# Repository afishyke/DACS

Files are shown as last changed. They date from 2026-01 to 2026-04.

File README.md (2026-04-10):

# DACS: Digital Automatic Changeover Switch

DACS is a discrete-logic power changeover controller that monitors grid health and switches loads between mains and inverter/battery supply. It is designed to avoid relay chatter by requiring sustained bad/good conditions before switching.

The full finite state machine (FSM), Boolean equations, and timing behavior are documented in `FSM/README.md`.

## What this project is

- A hardware-first automatic changeover system (no microcontroller in the switching core).
- A three-block architecture: sensing and conditioning, FSM decision logic, and relay output stage.
- A validated FSM implementation in both Logisim and Verilog.
- A delay-justification analysis pipeline for power-quality disturbance datasets.

## Visual overview

### 1) Full hardware architecture (KiCad)

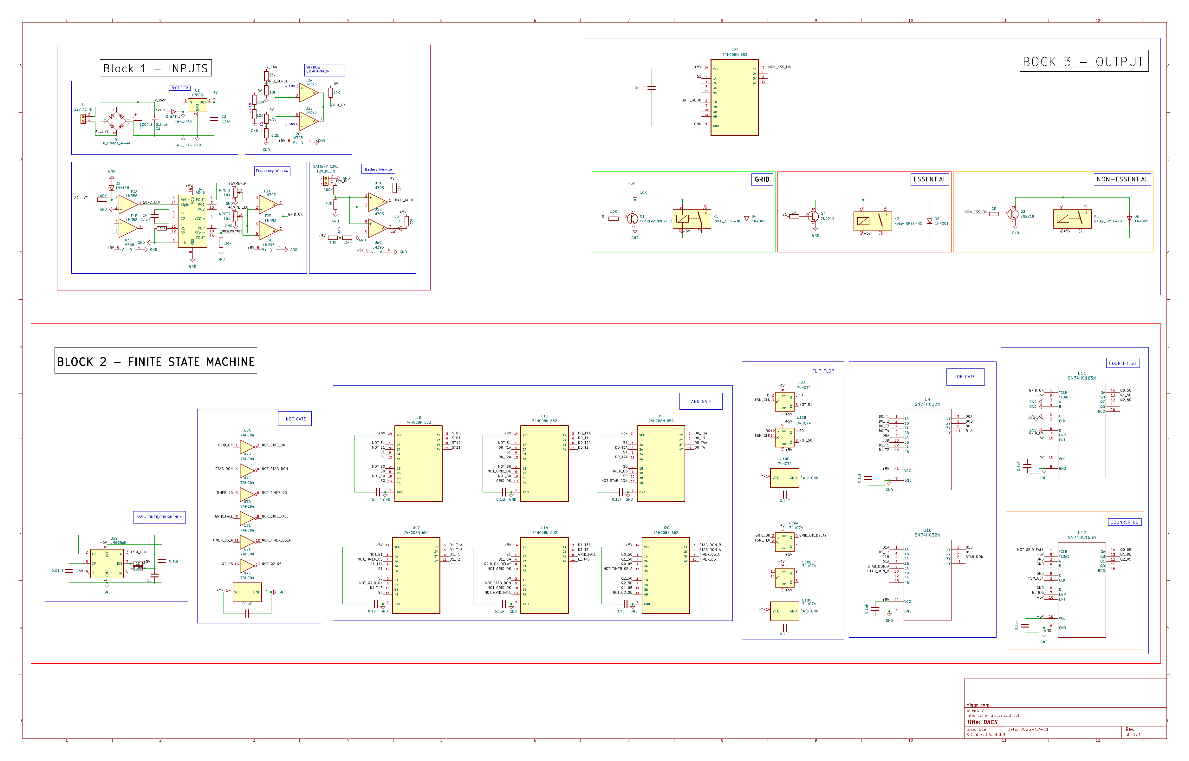
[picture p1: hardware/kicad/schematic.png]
DACS full schematic


### 2) GRID_OK comparator generation (LTspice)

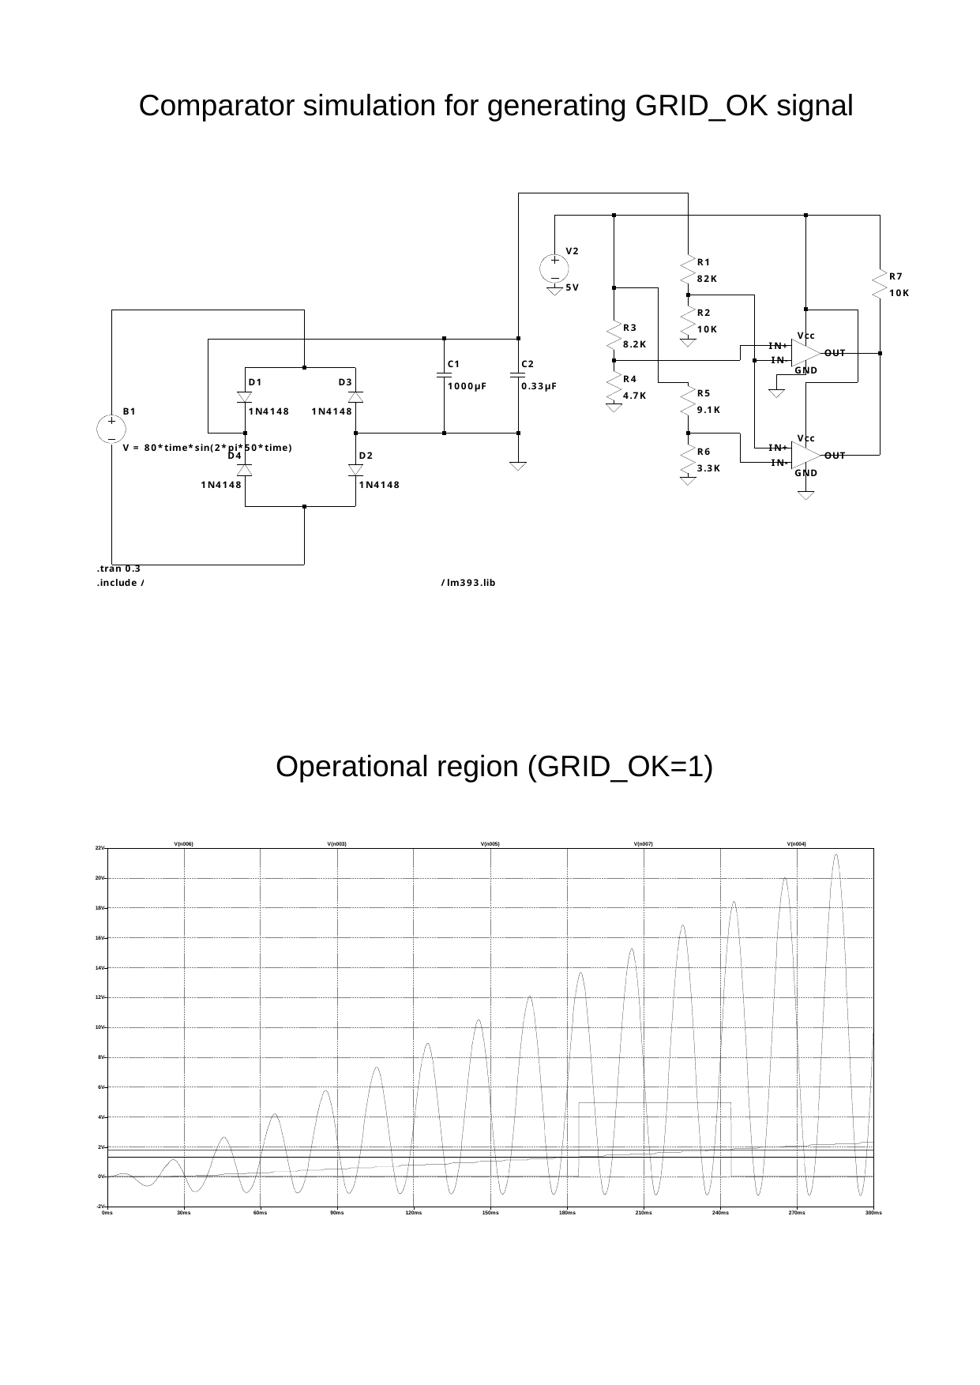
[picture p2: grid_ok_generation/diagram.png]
GRID_OK comparator simulation


### 3) Power-quality context plot

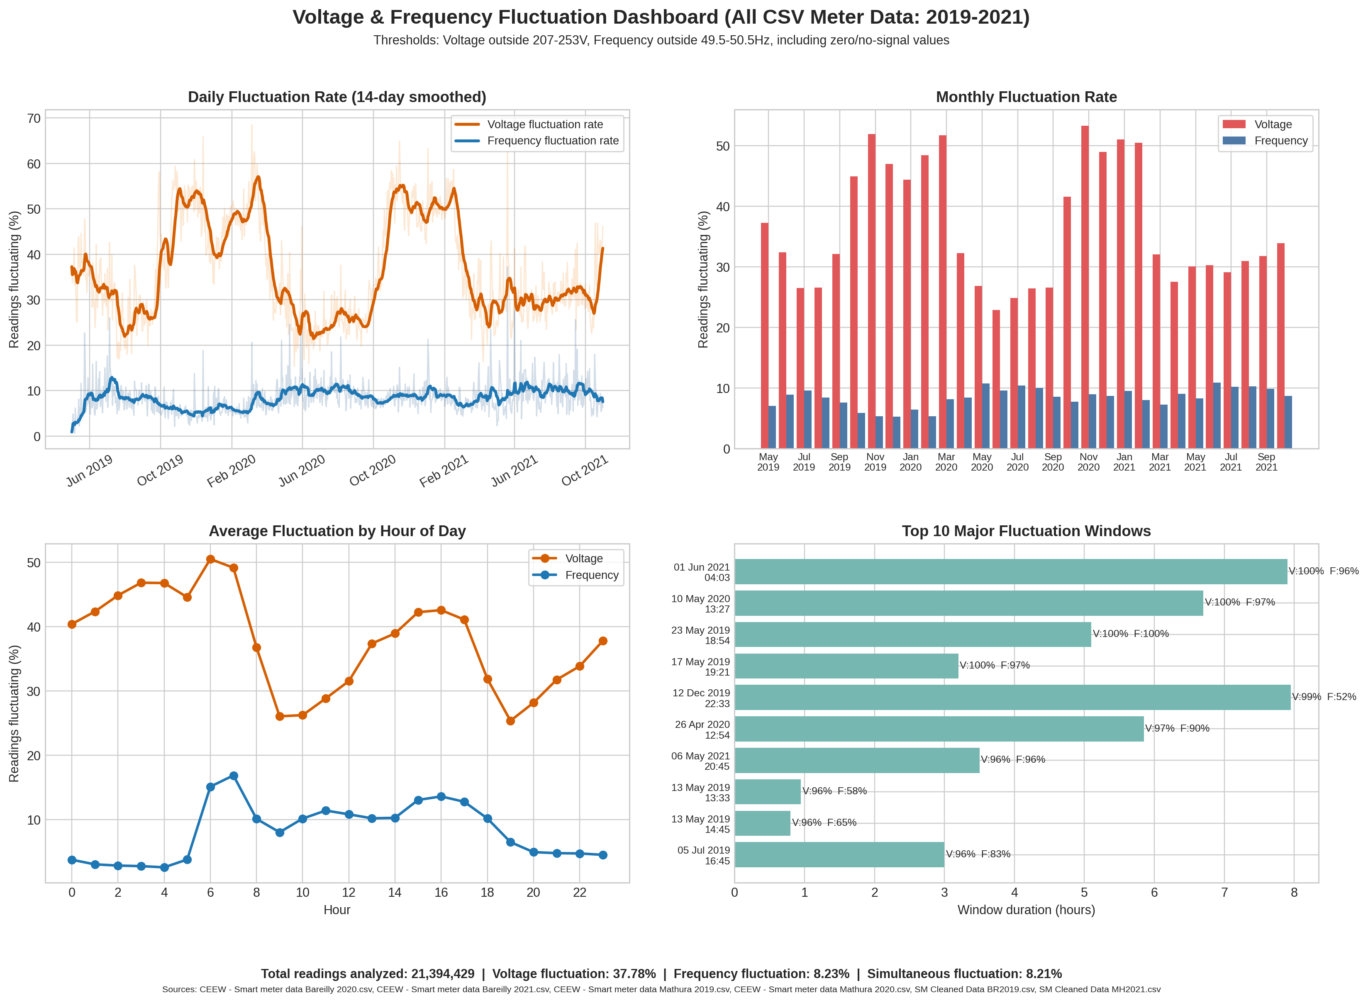
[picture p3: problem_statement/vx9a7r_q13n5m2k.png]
Problem statement plot


### 4) Disturbance class signal examples (delay analysis)

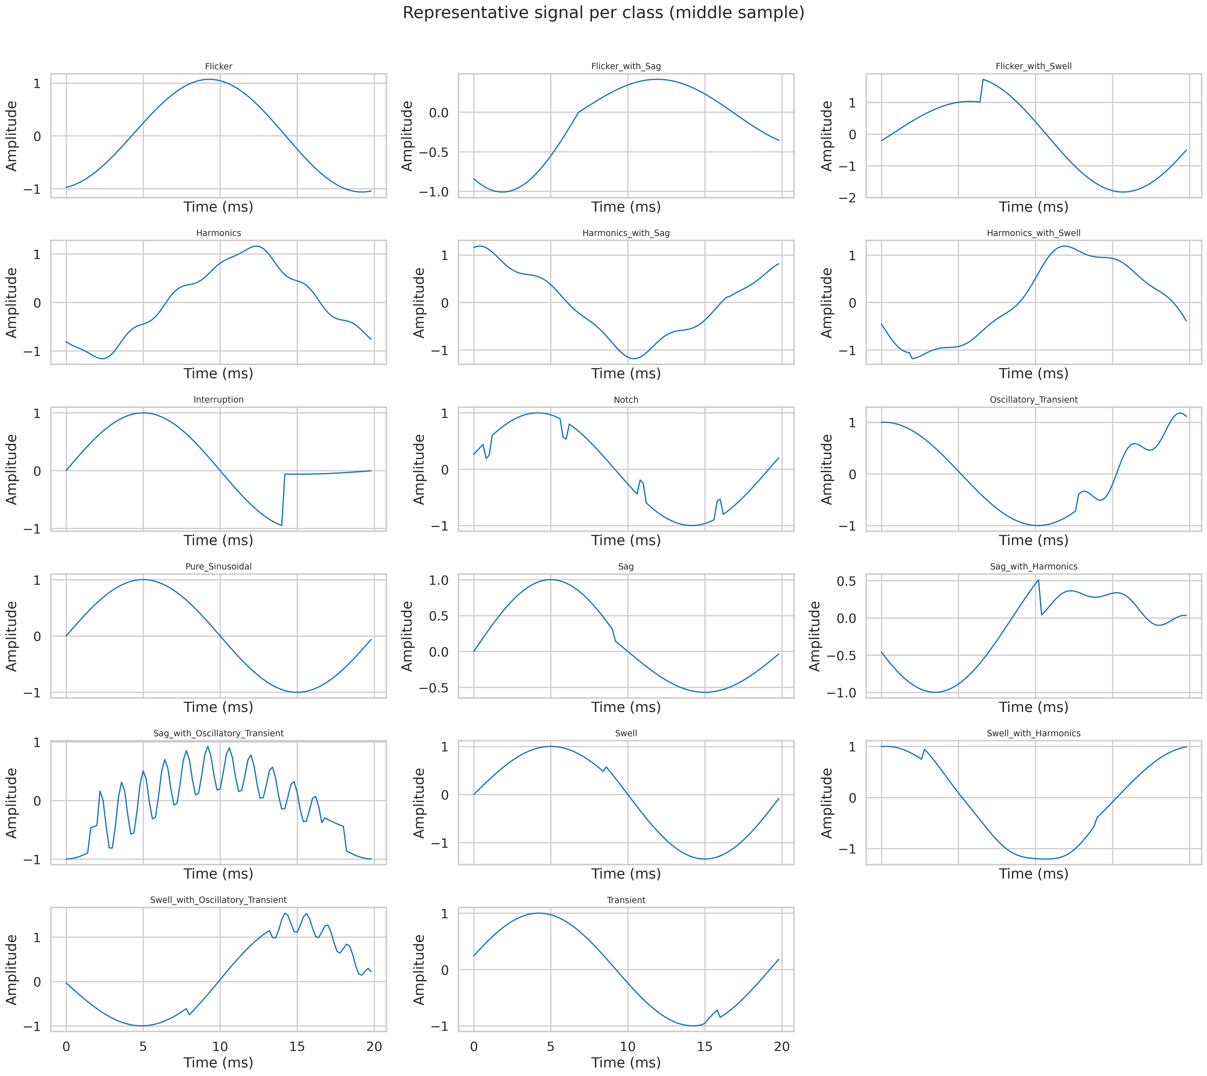
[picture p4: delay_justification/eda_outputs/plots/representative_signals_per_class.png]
Representative signals by class


## Repository map

- `hardware/kicad/`: complete KiCad design (`.kicad_sch`, `.kicad_pcb`, exports).
- `grid_ok_generation/`: LTspice comparator model and generated diagram for `GRID_OK` logic.
- `simulations/logisim/`: Logisim-evolution FSM implementation.
- `simulations/verilog/`: synthesizable FSM RTL (`FSM_Grid_Stability_v2.v`).
- `simulations/ltspice/`: LTspice analog simulation files.
- `FSM/`: equation-level FSM documentation.
- `problem_statement/`: source image/script + data citation used in early framing.
- `delay_justification/`: EDA script outputs, plots, and reports for timing-delay defensibility.

## How DACS works (end-to-end)

1. **Input conditioning (Block 1):** rectifies and scales AC sense, checks voltage window and frequency window, and verifies battery level.
2. **Grid health flag generation:** combines voltage + frequency validity into a digital `GRID_OK` signal.
3. **FSM logic (Block 2):** samples `GRID_OK` on `FSM_CLK`, uses state memory + counters to enforce delay windows.
4. **Output drive (Block 3):** relay drivers route power source and shed non-essential load during backup operation.

## Core timing and threshold numbers

- FSM clock is approximately 5 Hz (report uses 5 Hz for verification, i.e. 200 ms/cycle).
- Fault confirmation window: 3 cycles (`~600 ms` at 5 Hz).
- Recovery confirmation window: 5 cycles (`~1.0 s` at 5 Hz).
- Voltage monitor window used in the design documentation is approximately:
  - upper threshold: `~4.08 V`
  - lower threshold: `~2.78 V`

Clock equation used in design notes:

$$
f = \frac{1.44}{(R_a + 2R_b)C}
$$

With `R_a = 1k\Omega`, `R_b = 150k\Omega`, `C = 1\mu F`:

$$
f \approx 4.8\,\text{Hz}, \quad T = \frac{1}{f} \approx 0.21\,\text{s}
$$

## FSM states (high level)

| State | Bits | Meaning |
| --- | --- | --- |
| ST00 | `00` | Grid mode (normal operation) |
| ST01 | `01` | Grid fault detected, waiting for confirmation |
| ST10 | `10` | Backup mode (grid confirmed bad) |
| ST11 | `11` | Grid returned, waiting for stability confirmation |

Transition intent:

- `ST00 -> ST01`: grid falls.
- `ST01 -> ST10`: fault persists until fault timer expires.
- `ST10 -> ST11`: grid returns.
- `ST11 -> ST00`: grid remains healthy until stability timer done.
- Fast rollback paths protect against short disturbances (`ST01 -> ST00`, `ST11 -> ST10`).

For the complete Boolean equations (`GRID_FALL`, `TIMER_05`, `STABILITY_DONE`, `D0`, `D1`, all term-level equations), see `FSM/README.md`.

## Verification artifacts

From the FSM verification campaign artifacts in this repository:

- 2779 automated checks reported, 0 mismatches.
- State occupancy observed:
  - ST00: 169 cycles (42.5%)
  - ST01: 96 cycles (24.1%)
  - ST10: 79 cycles (19.9%)
  - ST11: 54 cycles (13.6%)

Detailed state equations and transition logic are documented in `FSM/README.md`.

## Delay-justification EDA (dataset side)

The `delay_justification/` folder contains a full analysis pipeline for disturbance classes (17 classes, one-cycle signals at 5 kHz sampling). It supports the claim that non-zero observation windows are required before robust disturbance discrimination.

Useful plots include:

- `delay_justification/eda_outputs/plots/representative_signals_per_class.png`
- `delay_justification/eda_outputs/plots/overlay_transient_related_classes.png`
- `delay_justification/eda_outputs/plots/scatter_transient_vs_sagswell_derivative_vs_spectralspread.png`

## Main source files

- Verilog FSM: `simulations/verilog/FSM_Grid_Stability_v2.v`
- Logisim FSM: `simulations/logisim/FSM_Grid_Stabilityiteration_FINAL112233.XML (1).circ`
- Comparator LTspice: `grid_ok_generation/comparator_grid_ok.asc`
- Hardware schematic source: `hardware/kicad/schematic.kicad_sch`

## References and citations

- FSM implementation references: `simulations/verilog/FSM_Grid_Stability_v2.v`, `simulations/logisim/FSM_Grid_Stabilityiteration_FINAL112233.XML (1).circ`
- Smart-meter citation used in problem framing: `problem_statement/citations.txt`
- Comparator SPICE model source note: `grid_ok_generation/resources.txt`

## License

MIT. See `LICENSE`.

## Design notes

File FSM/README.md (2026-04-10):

# FSM Design Notes (DACS)

This document explains the DACS finite state machine in equation-level detail.

## FSM purpose

The FSM prevents nuisance source switching by converting instantaneous grid status (`GRID_OK`) into delayed, state-aware switching decisions:

- confirm a **fault** only after 3 consecutive bad cycles,
- confirm a **recovery** only after 5 consecutive good cycles.

At the verification clock (`5 Hz`), those windows are `600 ms` and `1.0 s`.

## FSM implementation view

Implementation is available as a digital circuit and RTL:

- Logisim: `../simulations/logisim/FSM_Grid_Stabilityiteration_FINAL112233.XML (1).circ`
- Verilog: `../simulations/verilog/FSM_Grid_Stability_v2.v`

## State encoding

Let `S1 S0` be the current state bits.

| State | Bits | Meaning |
| --- | --- | --- |
| ST00 | `00` | Grid active, normal operation |
| ST01 | `01` | Grid fault seen, waiting for confirmation |
| ST10 | `10` | Backup mode, grid confirmed bad |
| ST11 | `11` | Grid returned, waiting for stability confirmation |

Decoded state equations:

$$
\begin{aligned}
ST00 &= \overline{S1}\,\overline{S0} \\
ST01 &= \overline{S1}\,S0 \\
ST10 &= S1\,\overline{S0} \\
ST11 &= S1\,S0
\end{aligned}
$$

## Timing base equations

Report verification clock:

$$
T_{clk}=\frac{1}{5}=200\,\text{ms}
$$

Delay windows:

$$
t_{fault}=3\,T_{clk}=600\,\text{ms}, \qquad t_{recovery}=5\,T_{clk}=1.0\,\text{s}
$$

Hardware oscillator formula used in the project:

$$
f=\frac{1.44}{(R_a+2R_b)C}
$$

With `R_a=1k\Omega`, `R_b=150k\Omega`, `C=1\mu F`, this yields about `4.8 Hz` (close to the 5 Hz verification clock).

## Derived internal signals (from implementation)

These are the core helper equations that drive the FSM transitions.

$$
GRID\_FALL = \overline{GRID\_OK}\;\&\;GRID\_delay
$$

$$
STABILITY\_DONE = (QA50\;\&\;QC50)\;|\;(QB50\;\&\;QC50)
$$

$$
TIMER\_05 = \overline{(QA05\;\&\;QB05)}\;\&\;\overline{QC05}
$$

Interpretation:

- `GRID_FALL`: one-cycle pulse on `GRID_OK` falling edge.
- `STABILITY_DONE`: high once recovery counter reaches count 5/6/7.
- `TIMER_05`: high while fault counter is still below the 3-cycle confirmation point.

Counter update equations (from RTL behavior):

$$
cnt50[k+1] =
\begin{cases}
0, & GRID\_OK=0 \\
(cnt50[k]+1) \bmod 8, & GRID\_OK=1
\end{cases}
$$

$$
cnt05[k+1] =
\begin{cases}
0, & GRID\_FALL=1 \\
(cnt05[k]+1) \bmod 6, & GRID\_OK=0\ \text{and}\ GRID\_FALL=0 \\
cnt05[k], & GRID\_OK=1\ \text{and}\ GRID\_FALL=0
\end{cases}
$$

## Next-state Boolean equations

### D0 equation

$$
\begin{aligned}
D0\_T1 &= \overline{S1}\,\overline{S0}\,\overline{GRID\_OK} \\
D0\_T2 &= S1\,\overline{S0}\,GRID\_OK \\
D0\_T3 &= \overline{S1}\,S0\,TIMER\_05\,\overline{GRID\_OK} \\
D0\_T4 &= S1\,S0\,\overline{STAB\_DONE}\,GRID\_OK \\
D0 &= D0\_T1\;|\;D0\_T2\;|\;D0\_T3\;|\;D0\_T4
\end{aligned}
$$

### D1 equation

$$
\begin{aligned}
D1\_T1 &= \overline{S1}\,S0\,\overline{TIMER\_05}\,\overline{GRID\_OK} \\
D1\_T2 &= S1\,\overline{S0} \\
D1\_T3 &= S1\,S0\,\overline{STAB\_DONE} \\
D1 &= D1\_T1\;|\;D1\_T2\;|\;D1\_T3
\end{aligned}
$$

## Equation consequences (operational meaning)

- `D0_T1`: from `ST00`, grid drop pushes machine toward `ST01`.
- `D0_T3`: keeps state in `ST01` while bad grid has not yet reached fault confirmation.
- `D1_T1`: once bad grid persists long enough, drives `ST01 -> ST10`.
- `D0_T2` + `D1_T2`: on grid return in `ST10`, drives `ST10 -> ST11`.
- `D0_T4` + `D1_T3`: keeps machine in `ST11` until recovery confirmation completes.

## Transition summary (practical)

- `ST00 + GRID_OK=0 -> ST01`
- `ST01 + GRID_OK=1 -> ST00`
- `ST01 + GRID_OK=0 + timer expired -> ST10`
- `ST10 + GRID_OK=1 -> ST11`
- `ST11 + GRID_OK=1 + STAB_DONE=1 -> ST00`
- `ST11 + GRID_OK=0 -> ST10`

Here, `STAB_DONE` is the same signal as `STABILITY_DONE`.

```mermaid
stateDiagram-v2
    [*] --> ST00
    ST00 --> ST01: GRID_OK = 0
    ST01 --> ST00: GRID_OK = 1
    ST01 --> ST10: GRID_OK = 0 and TIMER_05 = 0
    ST10 --> ST11: GRID_OK = 1
    ST11 --> ST00: GRID_OK = 1 and STABILITY_DONE = 1
    ST11 --> ST10: GRID_OK = 0
```

## Verification summary

- Extended run: `2779` checks, `0` mismatches.
- State occupancy:
  - `ST00`: 169 cycles (42.5%)
  - `ST01`: 96 cycles (24.1%)
  - `ST10`: 79 cycles (19.9%)
  - `ST11`: 54 cycles (13.6%)
- Transition counts observed:
  - `ST00 -> ST01`: 34
  - `ST01 -> ST00`: 26
  - `ST01 -> ST10`: 8
  - `ST10 -> ST11`: 13
  - `ST11 -> ST00`: 8
  - `ST11 -> ST10`: 5

State occupancy table:

| State | Cycles | Percentage |
| --- | ---: | ---: |
| ST00 | 169 | 42.5% |
| ST01 | 96 | 24.1% |
| ST10 | 79 | 19.9% |
| ST11 | 54 | 13.6% |

## Implementation files

- Verilog RTL: `../simulations/verilog/FSM_Grid_Stability_v2.v`
- Logisim circuit: `../simulations/logisim/FSM_Grid_Stabilityiteration_FINAL112233.XML (1).circ`

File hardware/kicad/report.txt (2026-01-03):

Plotted to '/home/abhishek/DACS/schematic/schematic.pdf'.

Plotted to '/home/abhishek/DACS/schematic/schematic.ps'.
Info: Done.
Info: Done.

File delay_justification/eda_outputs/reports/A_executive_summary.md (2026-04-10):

# A. Executive summary

- Inventory confirms 17 CSV class files, 1 MAT file, and 1 TXT metadata file.
- Classes are encoded directly in CSV filenames (exactly 17 class names).
- Each CSV has shape 1000 x 100; sample counts are balanced.
- Global amplitude range observed in waveform files: [-2.460116, 2.485719] (supports scaled/synthetic signal claim).
- With fs=5000 Hz and 100 samples/signal, each signal spans 20.000 ms (~1 cycle at 50 Hz).
- Transient-oriented features indicate strongest abrupt/localized behavior in classes containing Transient and in Notch; sag/swell classes look more sustained in-window.

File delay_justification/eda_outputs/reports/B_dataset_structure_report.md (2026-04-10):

# B. Dataset structure report

## Tree
```text
XPQRS/
├── eda_outputs
│   ├── plots
│   ├── reports
│   └── tables
├── 5Kfs_1Cycle_50f_1000Sam_1A.mat
├── Details.txt
├── Flicker.csv
├── Flicker_with_Sag.csv
├── Flicker_with_Swell.csv
├── Harmonics.csv
├── Harmonics_with_Sag.csv
├── Harmonics_with_Swell.csv
├── Interruption.csv
├── Notch.csv
├── Oscillatory_Transient.csv
├── Pure_Sinusoidal.csv
├── Sag.csv
├── Sag_with_Harmonics.csv
├── Sag_with_Oscillatory_Transient.csv
├── seed_pqd_eda.py
├── Swell.csv
├── Swell_with_Harmonics.csv
├── Swell_with_Oscillatory_Transient.csv
└── Transient.csv
```

## Manifest (from extracted root)
                                name                        relative_path file_type  size_bytes size_human                                likely_purpose
                         Flicker.csv                          Flicker.csv       csv     1828064    1.74 MB Per-class waveform matrix (signals x samples)
                Flicker_with_Sag.csv                 Flicker_with_Sag.csv       csv     1845224    1.76 MB Per-class waveform matrix (signals x samples)
              Flicker_with_Swell.csv               Flicker_with_Swell.csv       csv     1808478    1.72 MB Per-class waveform matrix (signals x samples)
                       Harmonics.csv                        Harmonics.csv       csv     1833542    1.75 MB Per-class waveform matrix (signals x samples)
              Harmonics_with_Sag.csv               Harmonics_with_Sag.csv       csv     1848883    1.76 MB Per-class waveform matrix (signals x samples)
            Harmonics_with_Swell.csv             Harmonics_with_Swell.csv       csv     1812584    1.73 MB Per-class waveform matrix (signals x samples)
                    Interruption.csv                     Interruption.csv       csv     1889934    1.80 MB Per-class waveform matrix (signals x samples)
                           Notch.csv                            Notch.csv       csv     1847524    1.76 MB Per-class waveform matrix (signals x samples)
           Oscillatory_Transient.csv            Oscillatory_Transient.csv       csv     1839624    1.75 MB Per-class waveform matrix (signals x samples)
                 Pure_Sinusoidal.csv                  Pure_Sinusoidal.csv       csv     1802000    1.72 MB Per-class waveform matrix (signals x samples)
                             Sag.csv                              Sag.csv       csv     1826423    1.74 MB Per-class waveform matrix (signals x samples)
              Sag_with_Harmonics.csv               Sag_with_Harmonics.csv       csv     1855000    1.77 MB Per-class waveform matrix (signals x samples)
  Sag_with_Oscillatory_Transient.csv   Sag_with_Oscillatory_Transient.csv       csv     1851764    1.77 MB Per-class waveform matrix (signals x samples)
                           Swell.csv                            Swell.csv       csv     1789009    1.71 MB Per-class waveform matrix (signals x samples)
            Swell_with_Harmonics.csv             Swell_with_Harmonics.csv       csv     1817852    1.73 MB Per-class waveform matrix (signals x samples)
Swell_with_Oscillatory_Transient.csv Swell_with_Oscillatory_Transient.csv       csv     1818603    1.73 MB Per-class waveform matrix (signals x samples)
                       Transient.csv                        Transient.csv       csv     1846158    1.76 MB Per-class waveform matrix (signals x samples)
      5Kfs_1Cycle_50f_1000Sam_1A.mat       5Kfs_1Cycle_50f_1000Sam_1A.mat       mat    11362502   10.84 MB           Consolidated tensor for all classes
                     seed_pqd_eda.py                      seed_pqd_eda.py        py       35082   34.26 KB                                       Unknown
                         Details.txt                          Details.txt       txt         891   891.00 B                  Dataset metadata/description

## Label encoding detection
- folder names: False
- filenames: True
- metadata table (Details.txt): True
- separate label file: False

## File schema and cleanliness
                                file                        relative_path           shape  column_count  dtype_summary  missing_values  duplicate_rows  empty_file  malformed_rows  non_numeric_cells         notes
      5Kfs_1Cycle_50f_1000Sam_1A.mat       5Kfs_1Cycle_50f_1000Sam_1A.mat 1000 x 100 x 17           100        float64               0            1000           0               0                  0 variable: Out
                         Flicker.csv                          Flicker.csv      1000 x 100           100        float64               0               0           0               0                  0              
                Flicker_with_Sag.csv                 Flicker_with_Sag.csv      1000 x 100           100        float64               0               0           0               0                  0              
              Flicker_with_Swell.csv               Flicker_with_Swell.csv      1000 x 100           100        float64               0               0           0               0                  0              
                       Harmonics.csv                        Harmonics.csv      1000 x 100           100        float64               0               0           0               0                  0              
              Harmonics_with_Sag.csv               Harmonics_with_Sag.csv      1000 x 100           100        float64               0               0           0               0                  0              
            Harmonics_with_Swell.csv             Harmonics_with_Swell.csv      1000 x 100           100        float64               0               0           0               0                  0              
                    Interruption.csv                     Interruption.csv      1000 x 100           100 float64, int64               0               0           0               0                  0              
                           Notch.csv                            Notch.csv      1000 x 100           100        float64               0               0           0               0                  0              
           Oscillatory_Transient.csv            Oscillatory_Transient.csv      1000 x 100           100        float64               0               0           0               0                  0              
                 Pure_Sinusoidal.csv                  Pure_Sinusoidal.csv      1000 x 100           100 float64, int64               0             999           0               0                  0              
                             Sag.csv                              Sag.csv      1000 x 100           100 float64, int64               0               0           0               0                  0              
              Sag_with_Harmonics.csv               Sag_with_Harmonics.csv      1000 x 100           100        float64               0               0           0               0                  0              
  Sag_with_Oscillatory_Transient.csv   Sag_with_Oscillatory_Transient.csv      1000 x 100           100        float64               0               0           0               0                  0              
                           Swell.csv                            Swell.csv      1000 x 100           100 float64, int64               0               0           0               0                  0              
            Swell_with_Harmonics.csv             Swell_with_Harmonics.csv      1000 x 100           100        float64               0               0           0               0                  0              
Swell_with_Oscillatory_Transient.csv Swell_with_Oscillatory_Transient.csv      1000 x 100           100        float64               0               0           0               0                  0              
                       Transient.csv                        Transient.csv      1000 x 100           100        float64               0               0           0               0                  0              

Detailed samples saved: `eda_outputs/tables/csv_sample_rows_first12.csv` and `eda_outputs/tables/mat_sample_signals_first12.csv`.

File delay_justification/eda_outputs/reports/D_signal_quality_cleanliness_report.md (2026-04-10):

# D. Signal quality / cleanliness report

- Empty files detected: 0
- Total malformed CSV rows: 0
- Total non-numeric CSV cells: 0
- Total missing values across data-bearing files: 0
- Total duplicate signal rows across CSV files (sum): 999

## Time-series schema facts
- samples per signal: 100
- inferred duration per signal from fs: 20.000 ms
- dominant frequency check on Pure_Sinusoidal reference: 50.000 Hz
- observed amplitude min/max across CSV signals: [-2.460116, 2.485719]
- Interpretation: waveform values are scaled (dimensionless), not raw volts.

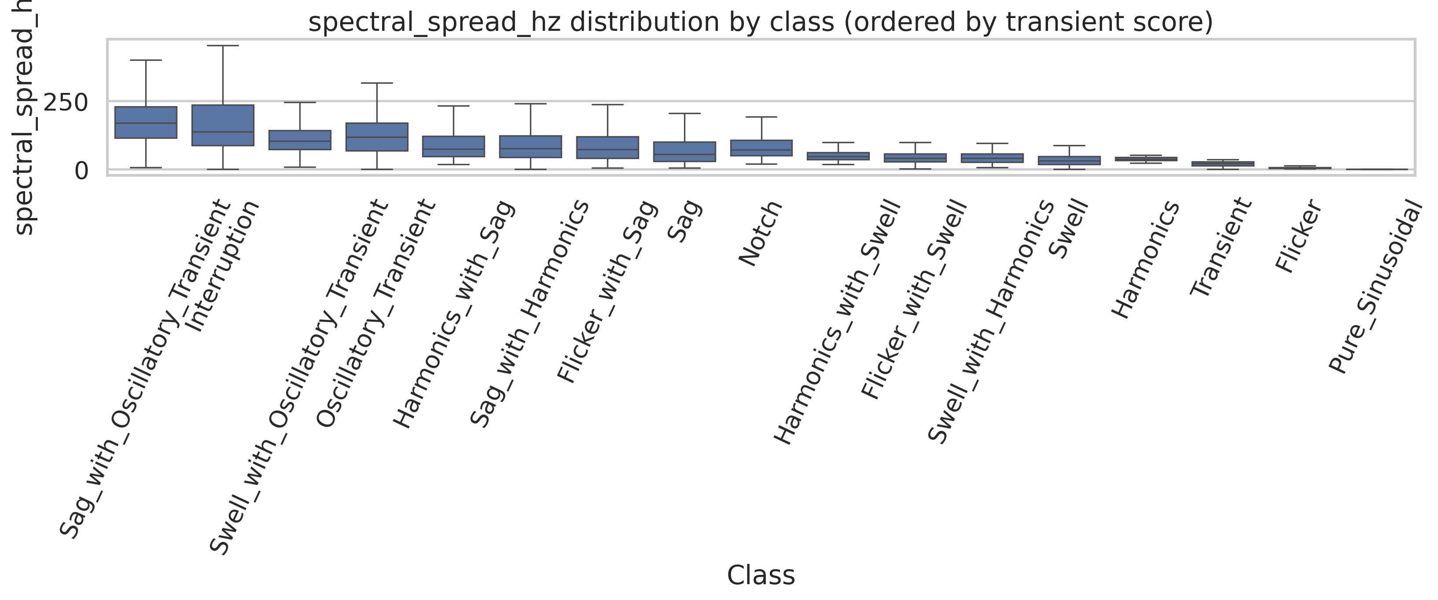
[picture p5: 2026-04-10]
delay_justification/eda_outputs/plots/metric_spectral_spread_hz_by_class.png

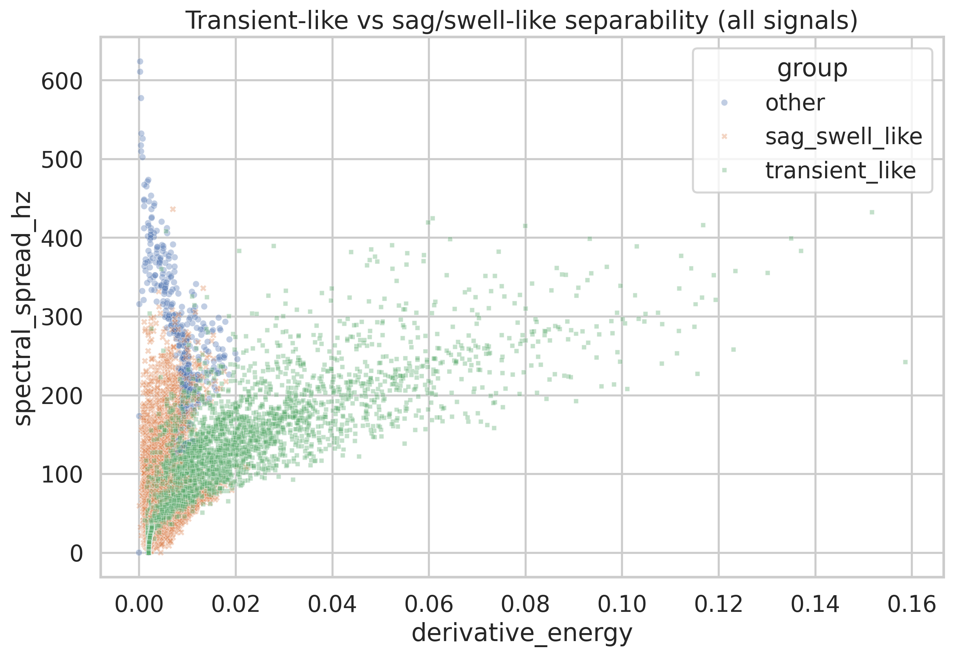
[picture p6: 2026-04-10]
delay_justification/eda_outputs/plots/scatter_transient_vs_sagswell_derivative_vs_spectralspread.png

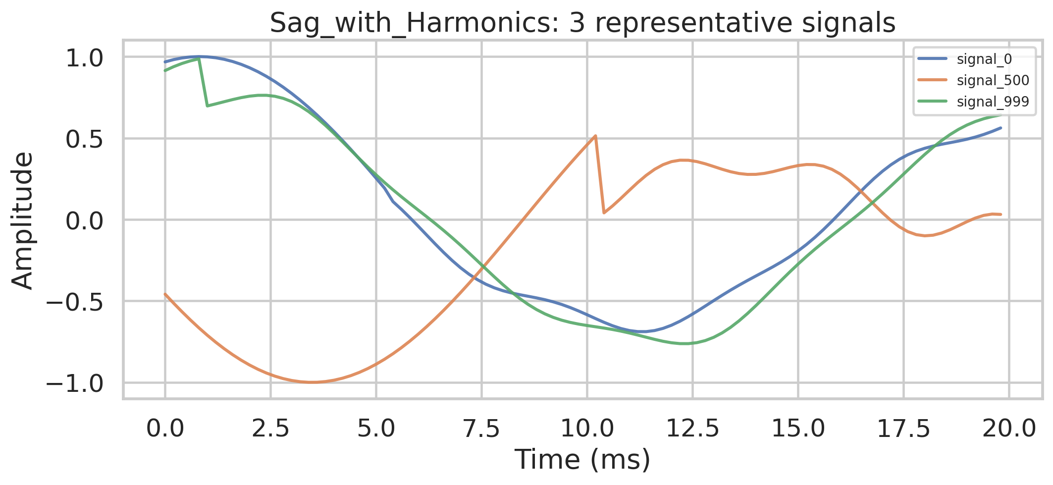
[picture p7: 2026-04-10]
delay_justification/eda_outputs/plots/per_class_3_representatives/Sag_with_Harmonics_three_representatives.png

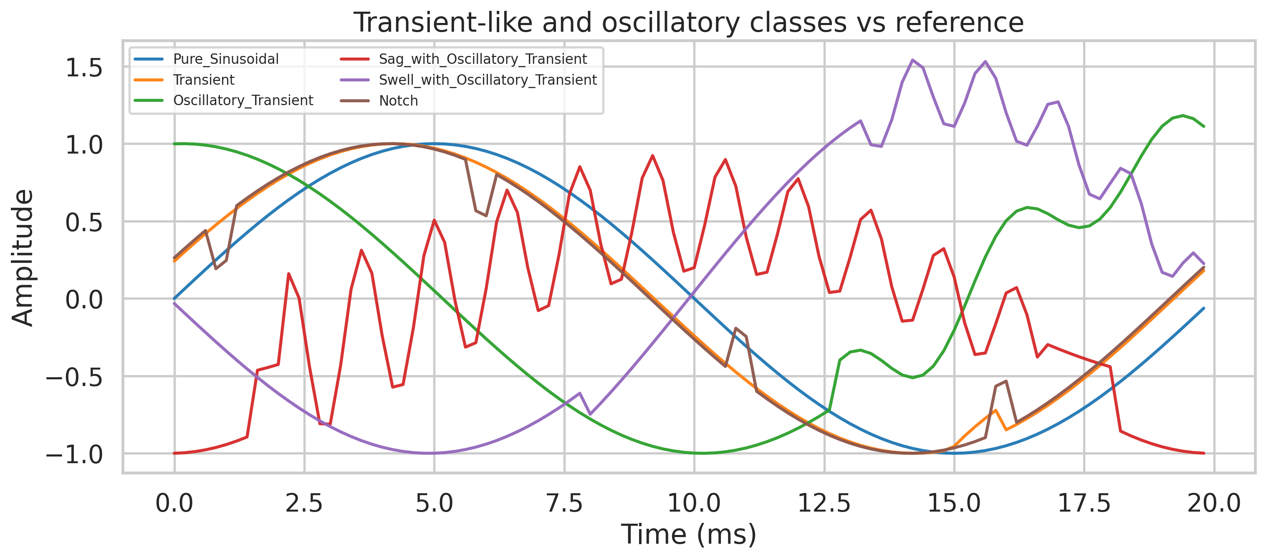
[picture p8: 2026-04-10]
delay_justification/eda_outputs/plots/overlay_transient_related_classes.png

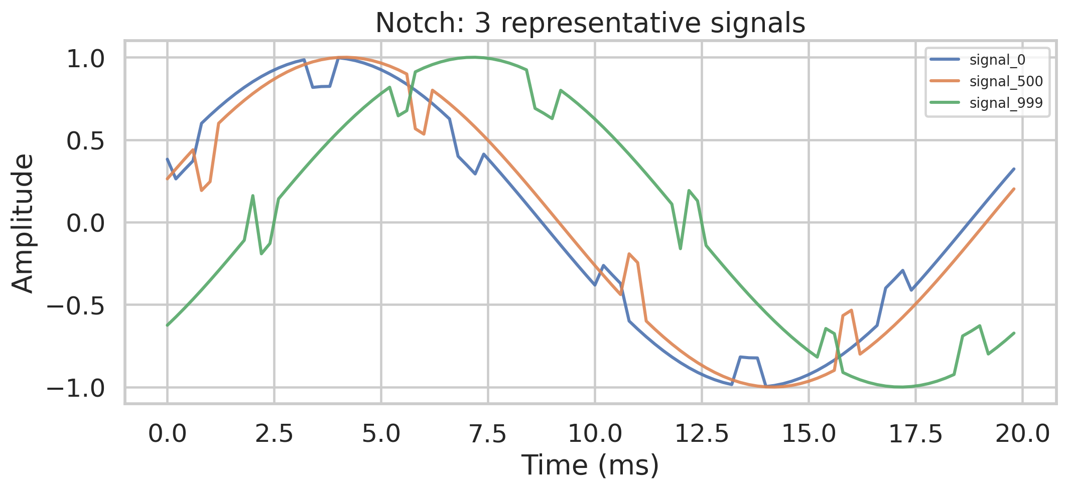
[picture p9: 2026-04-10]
delay_justification/eda_outputs/plots/per_class_3_representatives/Notch_three_representatives.png

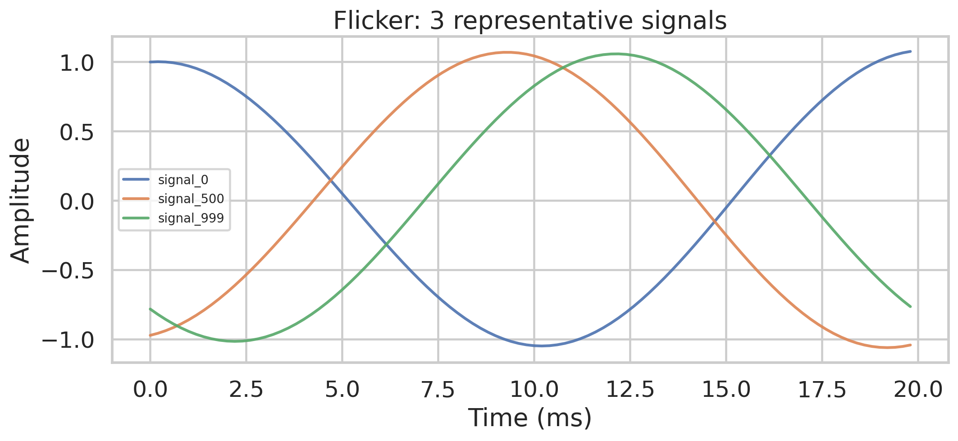
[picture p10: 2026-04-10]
delay_justification/eda_outputs/plots/per_class_3_representatives/Flicker_three_representatives.png

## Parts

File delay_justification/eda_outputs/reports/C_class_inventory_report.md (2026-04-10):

# C. Class inventory report

## Exact class list (from filenames)
- Flicker
- Flicker_with_Sag
- Flicker_with_Swell
- Harmonics
- Harmonics_with_Sag
- Harmonics_with_Swell
- Interruption
- Notch
- Oscillatory_Transient
- Pure_Sinusoidal
- Sag
- Sag_with_Harmonics
- Sag_with_Oscillatory_Transient
- Swell
- Swell_with_Harmonics
- Swell_with_Oscillatory_Transient
- Transient

## Counts and class type
                      class_name  sample_count  samples_per_signal class_type  mentions_transient  mentions_sag  mentions_swell  mentions_harmonics  mentions_flicker  mentions_notch_spike
                         Flicker          1000                 100       pure                   0             0               0                   0                 1                     0
                Flicker_with_Sag          1000                 100   compound                   0             1               0                   0                 1                     0
              Flicker_with_Swell          1000                 100   compound                   0             0               1                   0                 1                     0
                       Harmonics          1000                 100       pure                   0             0               0                   1                 0                     0
              Harmonics_with_Sag          1000                 100   compound                   0             1               0                   1                 0                     0
            Harmonics_with_Swell          1000                 100   compound                   0             0               1                   1                 0                     0
                    Interruption          1000                 100       pure                   0             0               0                   0                 0                     0
                           Notch          1000                 100       pure                   1             0               0                   0                 0                     1
           Oscillatory_Transient          1000                 100       pure                   1             0               0                   0                 0                     0
                 Pure_Sinusoidal          1000                 100       pure                   0             0               0                   0                 0                     0
                             Sag          1000                 100       pure                   0             1               0                   0                 0                     0
              Sag_with_Harmonics          1000                 100   compound                   0             1               0                   1                 0                     0
  Sag_with_Oscillatory_Transient          1000                 100   compound                   1             1               0                   0                 0                     0
                           Swell          1000                 100       pure                   0             0               1                   0                 0                     0
            Swell_with_Harmonics          1000                 100   compound                   0             0               1                   1                 0                     0
Swell_with_Oscillatory_Transient          1000                 100   compound                   1             0               1                   0                 0                     0
                       Transient          1000                 100       pure                   1             0               0                   0                 0                     0

- Balanced dataset by class counts: True
- Pure class count: 9
- Compound class count: 8

## Cautious name-based disturbance relevance (inference from names only)
- transient behavior: classes containing `Transient` plus `Notch`
- sustained undervoltage/sag: classes containing `Sag`
- sustained overvoltage/swell: classes containing `Swell`
- harmonic distortion: classes containing `Harmonics`
- flicker: classes containing `Flicker`
- notch/spike behavior: class `Notch`

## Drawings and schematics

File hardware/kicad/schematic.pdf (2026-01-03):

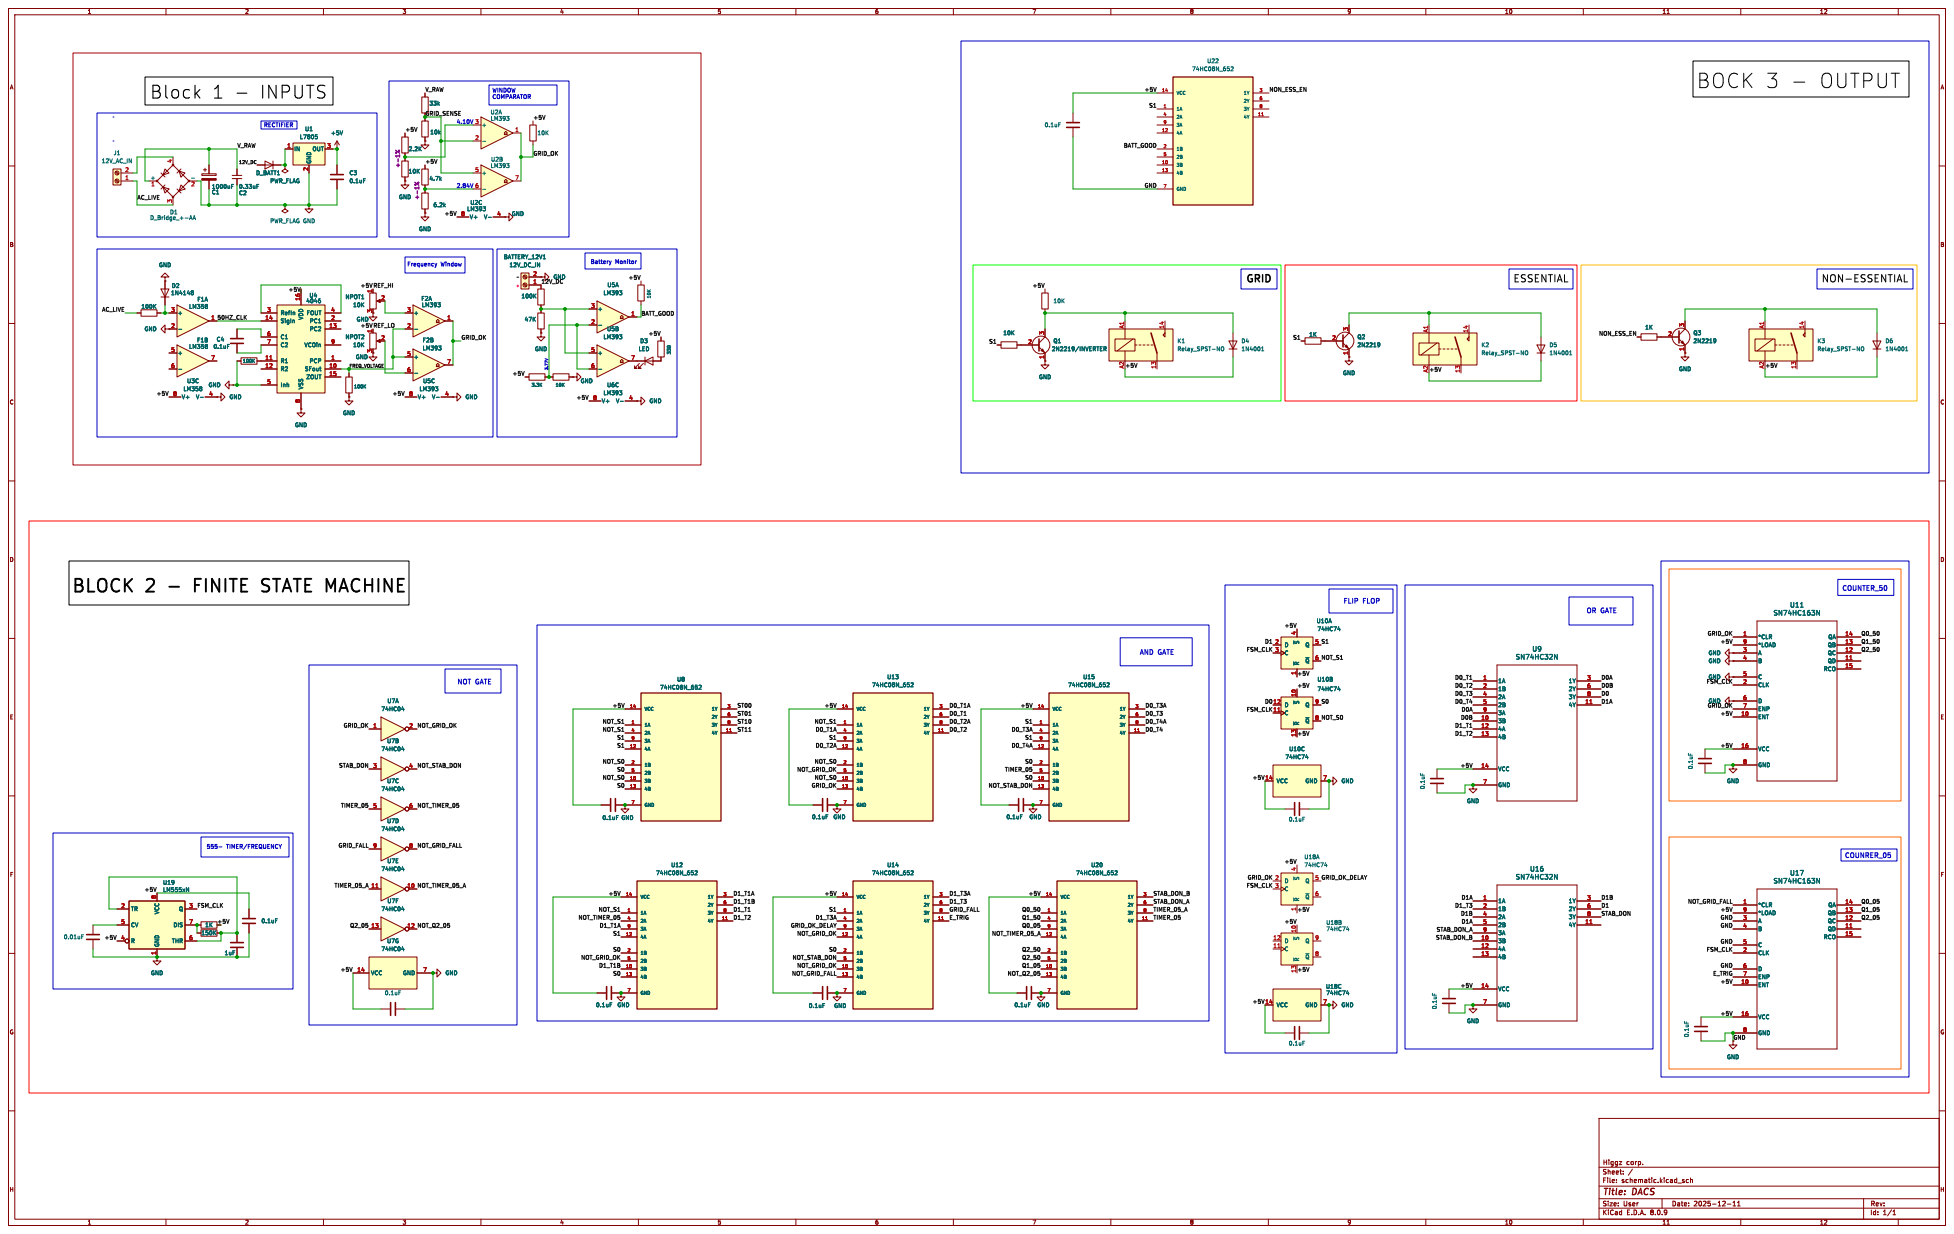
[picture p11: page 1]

File: schematic.kicad_sch Sheet: / Higgz corp.

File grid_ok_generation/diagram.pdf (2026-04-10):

# Comparator simulation for generating GRID_OK signal

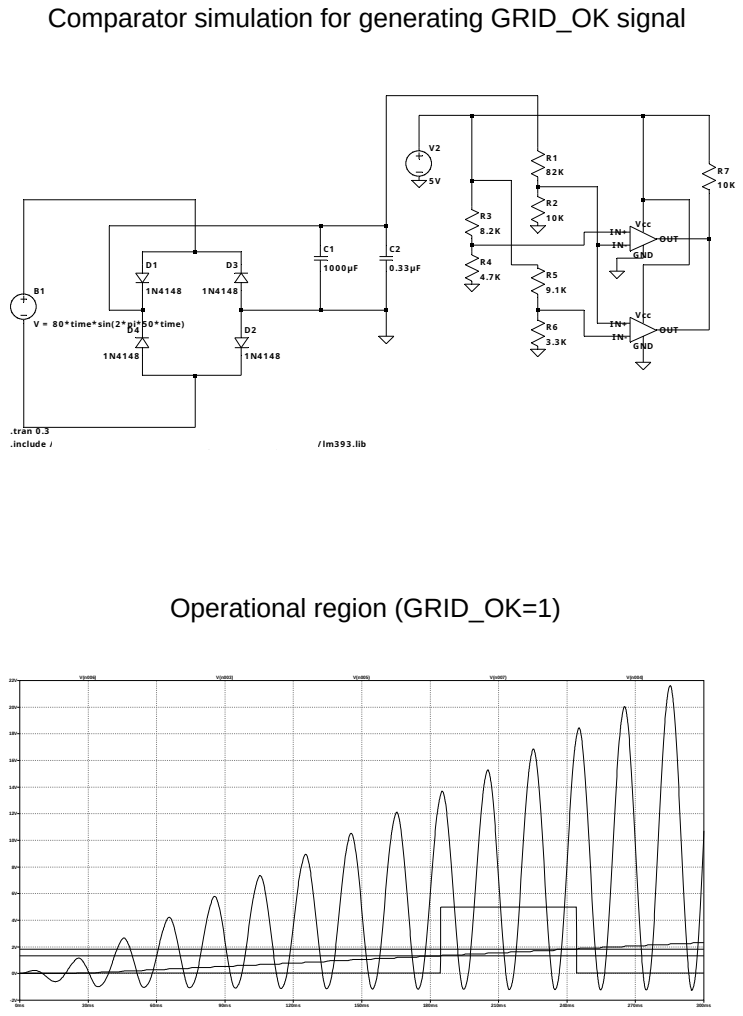
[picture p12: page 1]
Vcc; GND; OUT; Operational region (GRID_OK=1)

V = 8 0 * time* sin( 2 * pi* 5 0 * time)

.tran 0 .3
.include / home/ abhishek/ Documents/ LT spiceXVI I / funky/ LM3 9 3 / lm3 9 3 .lib

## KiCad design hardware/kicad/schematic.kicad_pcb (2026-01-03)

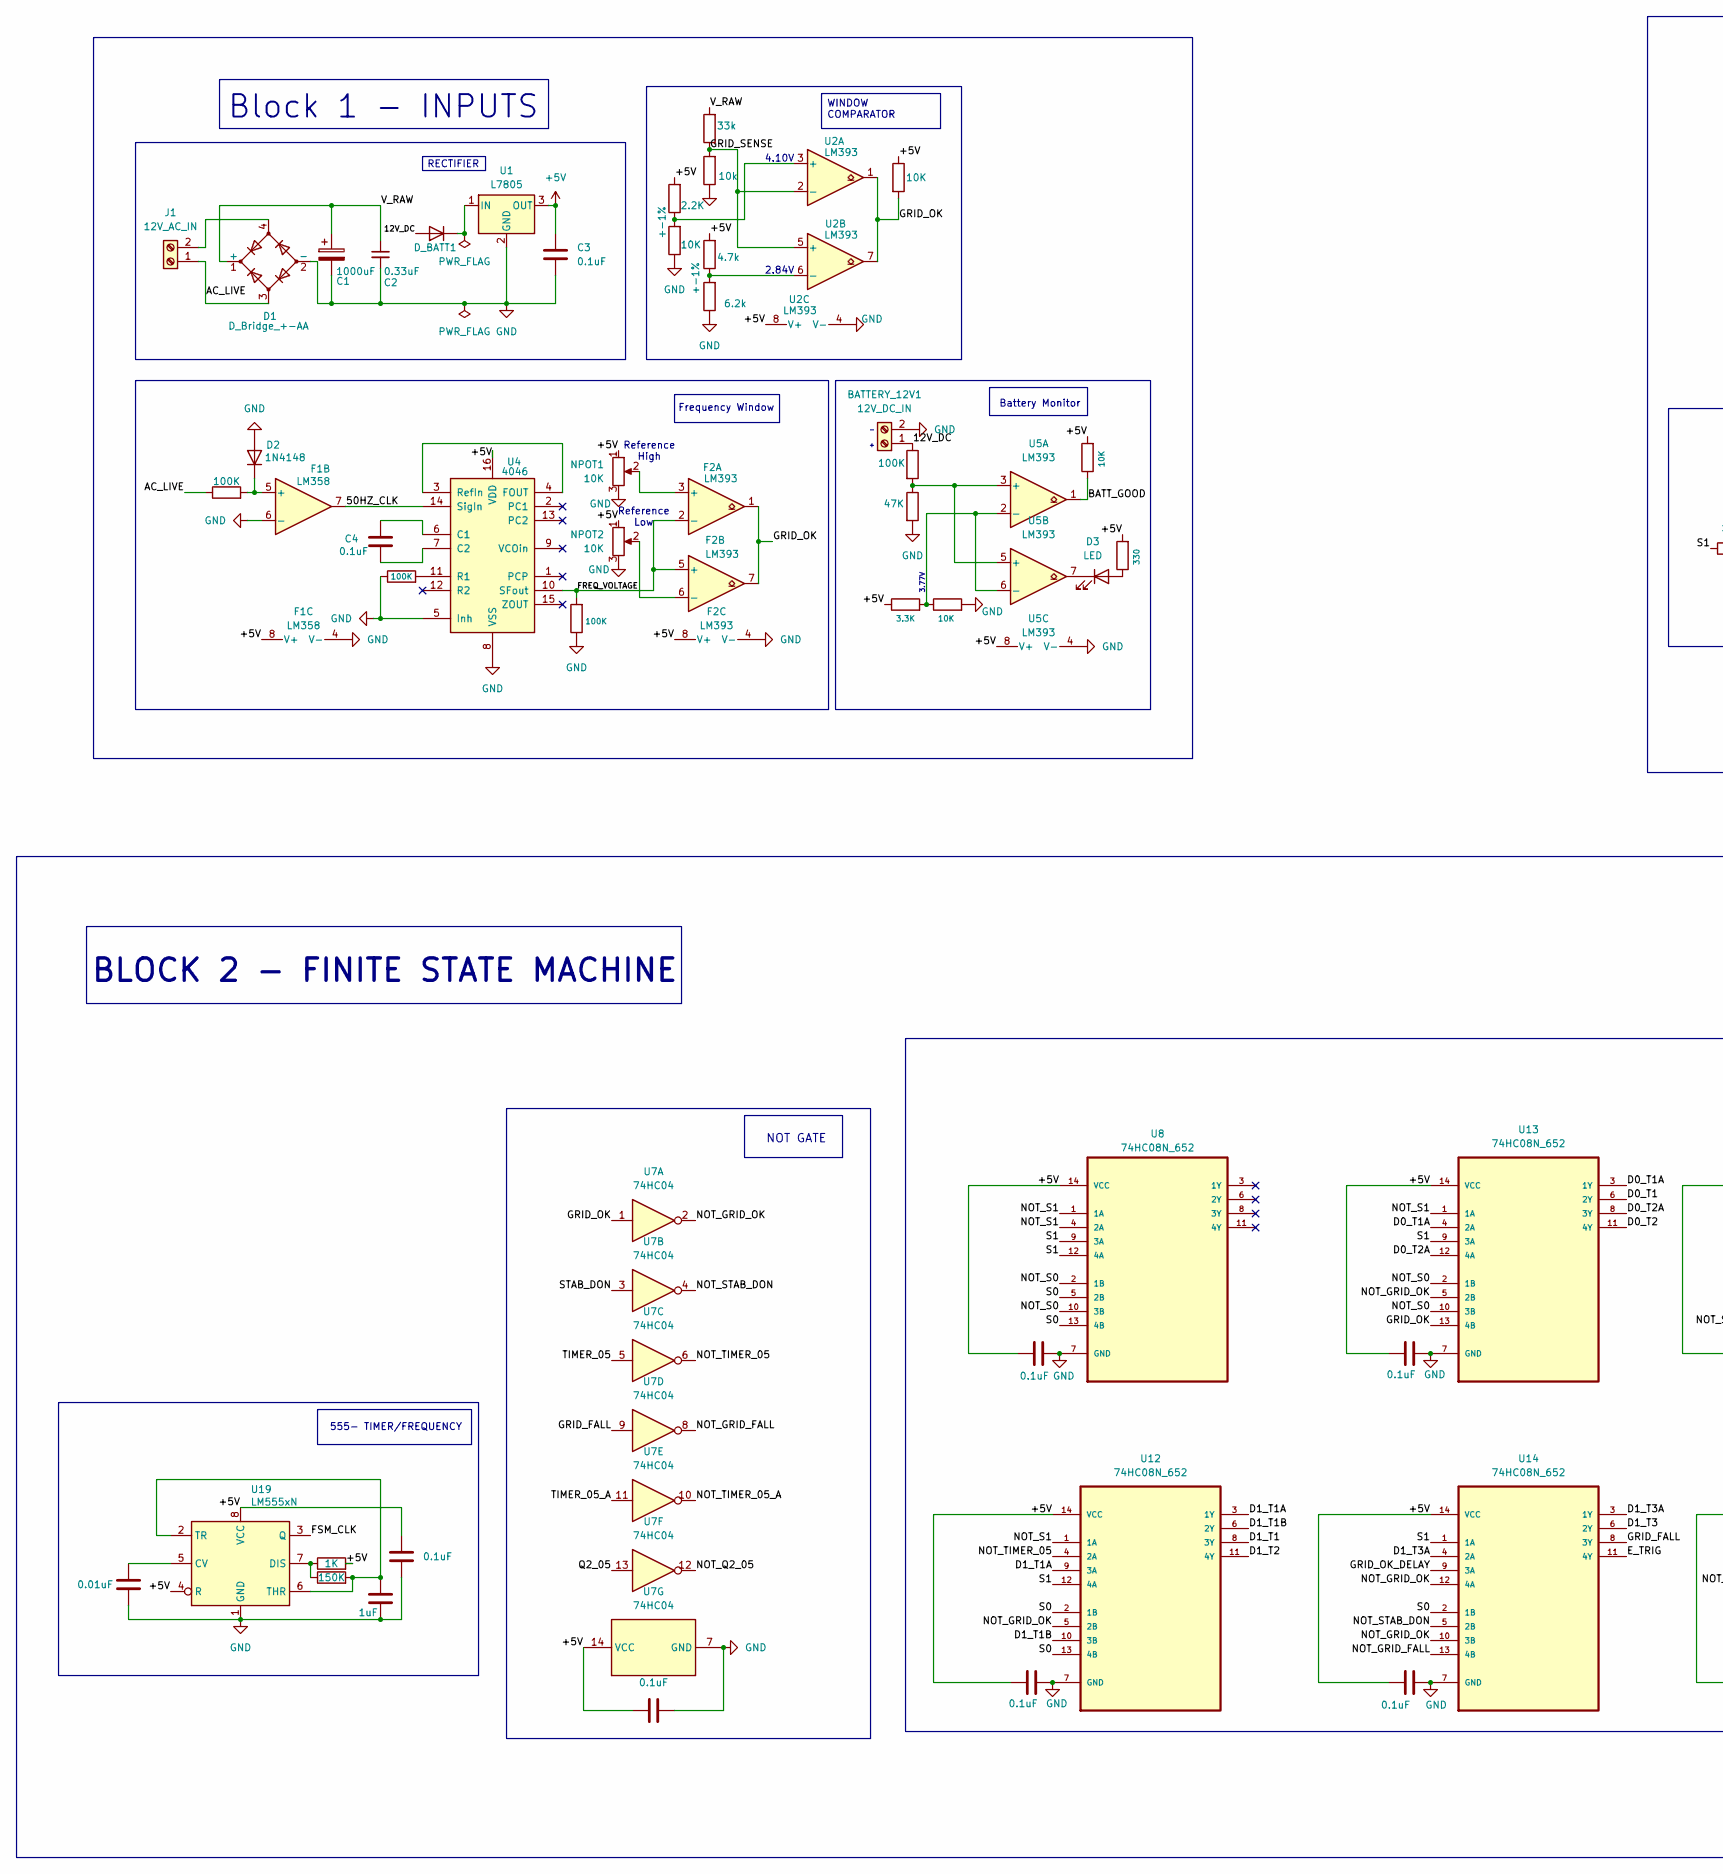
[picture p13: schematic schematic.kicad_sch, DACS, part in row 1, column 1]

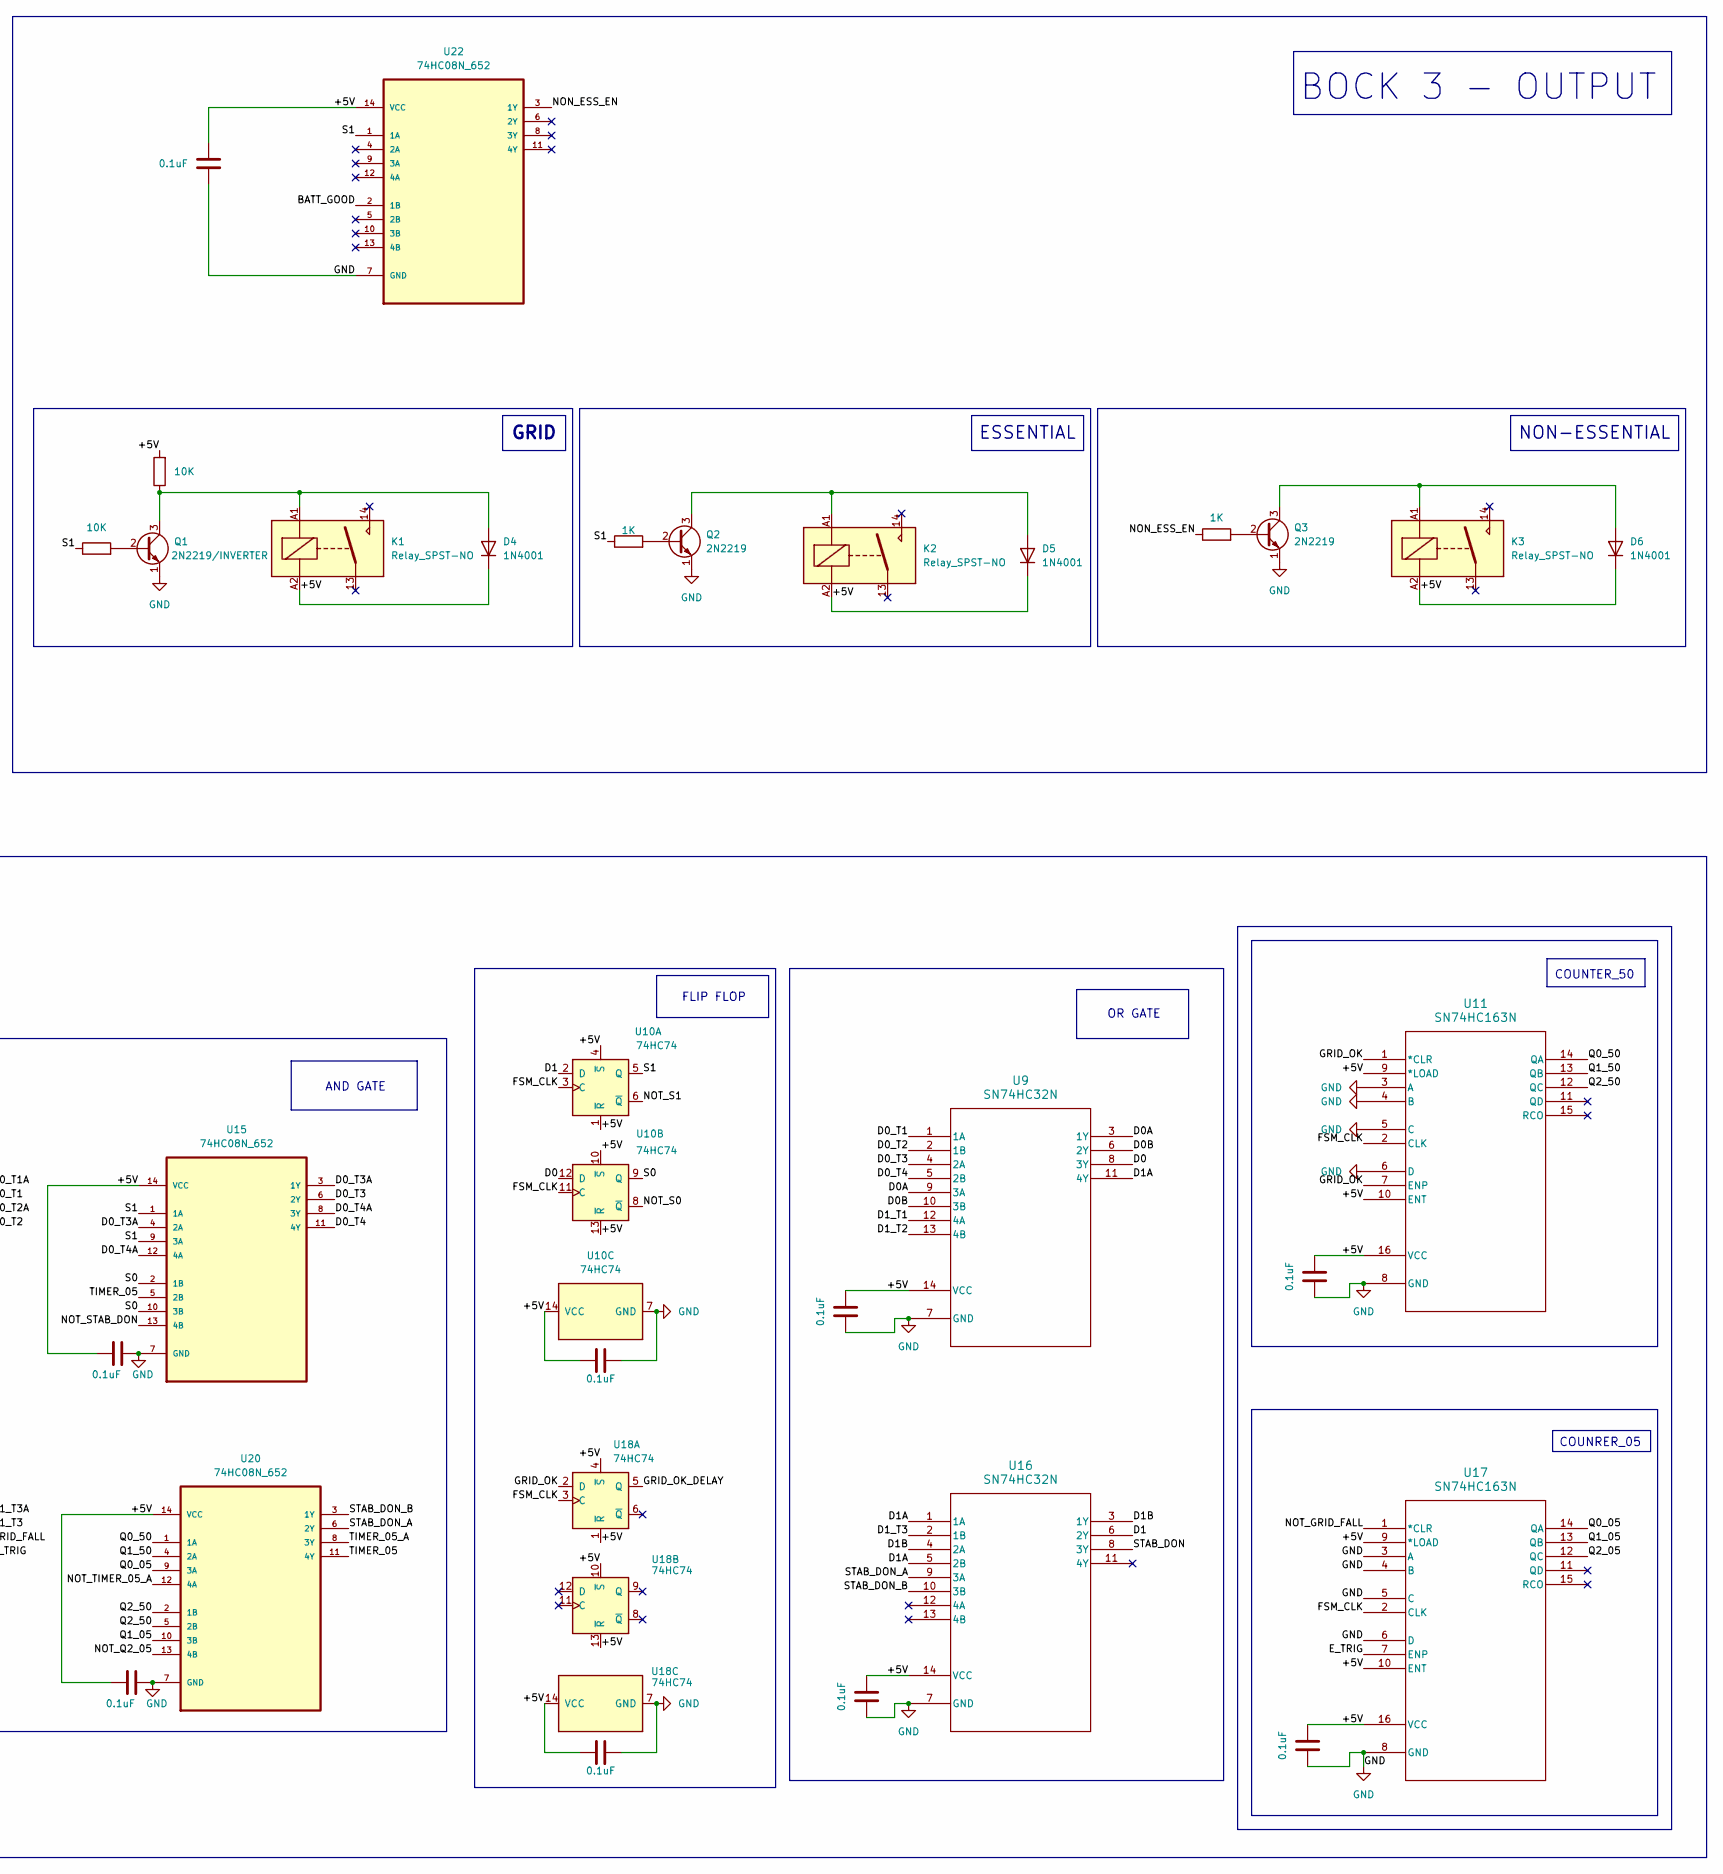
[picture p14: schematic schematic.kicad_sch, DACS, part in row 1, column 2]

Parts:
10k1: 4.7k; R_Axial_DIN0207_L6.3mm_D2.5mm_P7.62mm_Horizontal
10k2: 2.2K; R_Axial_DIN0207_L6.3mm_D2.5mm_P7.62mm_Horizontal
10k3: 10K; R_Axial_DIN0207_L6.3mm_D2.5mm_P7.62mm_Horizontal
BATTERY_12V1: 12V_DC_IN; R_Axial_DIN0207_L6.3mm_D2.5mm_P7.62mm_Horizontal
C1: 1000uF; R_Axial_DIN0207_L6.3mm_D2.5mm_P7.62mm_Horizontal
C2: 0.33uF; R_Axial_DIN0207_L6.3mm_D2.5mm_P7.62mm_Horizontal
C3, C4, C5, C6, C7, C8, C9, C10, C11, C12, C13, C14, C15, C16, C17, C19, C22: 0.1uF; C_Disc_D5.0mm_W2.5mm_P2.50mm
C18: 0.01uF; C_Disc_D5.0mm_W2.5mm_P2.50mm
C20: 1uF; C_Disc_D5.0mm_W2.5mm_P2.50mm
D1: D_Bridge_+-AA; Diode_Bridge_Round_D9.8mm
D2: 1N4148; D_DO-35_SOD27_P7.62mm_Horizontal
D3: LED; LED_D5.0mm
D4, D5, D6: 1N4001; D_DO-41_SOD81_P10.16mm_Horizontal
D_BATT1: 1N4007; D_DO-41_SOD81_P10.16mm_Horizontal
F1: LM358; DIP-8_W7.62mm
F2: LM393; DIP-8_W7.62mm
J1: 12V_AC_IN; Altech_AK100_1x02_P5.00mm
K1, K2, K3: Relay_SPST-NO; Relay_SPST_Omron_G5PZ
NPOT1, NPOT2: 10K; Potentiometer_Bourns_3296W_Vertical
Q1: 2N2219/INVERTER; TO-39-3
Q2, Q3: 2N2219; TO-39-3
R1: 33k; R_Axial_DIN0207_L6.3mm_D2.5mm_P7.62mm_Horizontal
R1k1: 6.2k; R_Axial_DIN0207_L6.3mm_D2.5mm_P7.62mm_Horizontal
R2, R9, R10, R14, R15: 10K; R_Axial_DIN0207_L6.3mm_D2.5mm_P7.62mm_Horizontal
R3, R4, R5, R6: 100K; R_Axial_DIN0207_L6.3mm_D2.5mm_P7.62mm_Horizontal
R7: 47K; R_Axial_DIN0207_L6.3mm_D2.5mm_P7.62mm_Horizontal
R8: 3.3K; R_Axial_DIN0207_L6.3mm_D2.5mm_P7.62mm_Horizontal
R11: 330; R_Axial_DIN0207_L6.3mm_D2.5mm_P7.62mm_Horizontal
R12, R16, R17: 1K; R_Axial_DIN0207_L6.3mm_D2.5mm_P7.62mm_Horizontal
R13: 150K; R_Axial_DIN0207_L6.3mm_D2.5mm_P7.62mm_Horizontal
R18: 10k; R_Axial_DIN0207_L6.3mm_D2.5mm_P7.62mm_Horizontal
U1: L7805; TO-220-3_Vertical
U2, U5: LM393; DIP-8_W7.62mm
U4: 4046; DIP-16_W7.62mm
U7: 74HC04; DIP-14_W7.62mm
U8, U12, U13, U14, U15, U20, U22: 74HC08N_652; DIP-14_W7.62mm; MPN 74HC08N,652
U9, U16: SN74HC32N; DIP-14_W7.62mm
U10, U18: 74HC74; DIP-14_W7.62mm
U11, U17: SN74HC163N; DIP-16_W7.62mm
U19: LM555xN; DIP-8_W7.62mm

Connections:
+5V: 10k1.2, 10k2.2, C3.1, C5.1, C6.1, C7.1, C8.1, C9.1, C10.1, C11.1, C12.1, C13.1, C14.1, C15.1, C16.1, C17.2, C19.1, C22.1, D4.1 (K), D5.1 (K), D6.1 (K), F1.8 (V+), F2.8 (V+), K1.A2, K2.A2, K3.A2, NPOT1.1, NPOT2.1, R2.1, R8.1, R10.2, R11.2, R12.2, R15.2, U1.3 (OUT), U2.8 (V+), U4.16 (VDD), U5.8 (V+), U7.14 (VCC), U8.14 (VCC), U9.14 (VCC), U10.1 (~R), U10.4 (~S), U10.10 (~S), U10.13 (~R), U10.14 (VCC), U11.9 (*LOAD), U11.10 (ENT), U11.16 (VCC), U12.14 (VCC), U13.14 (VCC), U14.14 (VCC), U15.14 (VCC), U16.14 (VCC), U17.9 (*LOAD), U17.10 (ENT), U17.16 (VCC), U18.1 (~R), U18.4 (~S), U18.10 (~S), U18.13 (~R), U18.14 (VCC), U19.4 (R), U19.8 (VCC), U20.14 (VCC), U22.14 (VCC); also elsewhere on the board
/12V_DC: BATTERY_12V1.1, D_BATT1.2 (A), R6.1
/50HZ_CLK: F1.1, F1.7, U4.14 (SigIn)
/AC_LIVE: D1.3, J1.1, R3.1
/BATT_GOOD: R10.1, U5.1, U22.2 (1B)
/D0: U9.8 (3Y), U10.12 (D)
/D0A: U9.3 (1Y), U9.9 (3A)
/D0B: U9.6 (2Y), U9.10 (3B)
/D0_T1: U9.1 (1A), U13.6 (2Y)
/D0_T1A: U13.3 (1Y), U13.4 (2A)
/D0_T2: U9.2 (1B), U13.11 (4Y)
/D0_T2A: U13.8 (3Y), U13.12 (4A)
/D0_T3: U9.4 (2A), U15.6 (2Y)
/D0_T3A: U15.3 (1Y), U15.4 (2A)
/D0_T4: U9.5 (2B), U15.11 (4Y)
/D0_T4A: U15.8 (3Y), U15.12 (4A)
/D1: U10.2 (D), U16.6 (2Y)
/D1A: U9.11 (4Y), U16.1 (1A), U16.5 (2B)
/D1B: U16.3 (1Y), U16.4 (2A)
/D1_T1: U9.12 (4A), U12.8 (3Y)
/D1_T1A: U12.3 (1Y), U12.9 (3A)
/D1_T1B: U12.6 (2Y), U12.10 (3B)
/D1_T2: U9.13 (4B), U12.11 (4Y)
/D1_T3: U14.6 (2Y), U16.2 (1B)
/D1_T3A: U14.3 (1Y), U14.4 (2A)
/E_TRIG: U14.11 (4Y), U17.7 (ENP)
/FREQ_VOLTAGE: F2.2 (-), F2.5 (+), R5.2, U4.10 (SFout)
/FSM_CLK: U10.3 (C), U10.11 (C), U11.2 (CLK), U17.2 (CLK), U18.3 (C), U19.3 (Q)
/GRID_FALL: U7.9, U14.8 (3Y)
/GRID_OK: F2.1, F2.7, R2.2, U2.1, U2.7, U7.1, U11.1 (*CLR), U11.7 (ENP), U13.13 (4B), U18.2 (D)
/GRID_OK_DELAY: U14.9 (3A), U18.5 (Q)
/GRID_SENSE: R1.1, R18.2, U2.2 (-), U2.5 (+)
/NON_ESS_EN: R17.1, U22.3 (1Y)
/NOT_GRID_FALL: U7.8, U14.13 (4B), U17.1 (*CLR)
/NOT_GRID_OK: U7.2, U12.5 (2B), U13.5 (2B), U14.10 (3B), U14.12 (4A)
/NOT_Q2_05: U7.12, U20.13 (4B)
/NOT_S0: U8.2 (1B), U8.10 (3B), U10.8 (~Q), U13.2 (1B), U13.10 (3B)
/NOT_S1: U8.1 (1A), U8.4 (2A), U10.6 (~Q), U12.1 (1A), U13.1 (1A)
/NOT_STAB_DON: U7.4, U14.5 (2B), U15.13 (4B)
/NOT_TIMER_05: U7.6, U12.4 (2A)
/NOT_TIMER_05_A: U7.10, U20.12 (4A)
/Q0_05: U17.14 (QA), U20.9 (3A)
/Q0_50: U11.14 (QA), U20.1 (1A)
/Q1_05: U17.13 (QB), U20.10 (3B)
/Q1_50: U11.13 (QB), U20.4 (2A)
/Q2_05: U7.13, U17.12 (QC)
/Q2_50: U11.12 (QC), U20.2 (1B), U20.5 (2B)
/S0: U8.5 (2B), U8.13 (4B), U10.9 (Q), U12.2 (1B), U12.13 (4B), U14.2 (1B), U15.2 (1B), U15.10 (3B)
/S1: R14.1, R16.1, U8.9 (3A), U8.12 (4A), U10.5 (Q), U12.12 (4A), U13.9 (3A), U14.1 (1A), U15.1 (1A), U15.9 (3A), U22.1 (1A)
/ST00: U8.3 (1Y)
/ST01: U8.6 (2Y)
/ST10: U8.8 (3Y)
/ST11: U8.11 (4Y)
/STAB_DON: U7.3, U16.8 (3Y)
/STAB_DON_A: U16.9 (3A), U20.6 (2Y)
/STAB_DON_B: U16.10 (3B), U20.3 (1Y)
/TIMER_05: U7.5, U15.5 (2B), U20.11 (4Y)
/TIMER_05_A: U7.11, U20.8 (3Y)
/V_RAW: C1.1, C2.1, D1.1 (+), R1.2; also elsewhere on the board
GND: 10k3.1, BATTERY_12V1.2, C1.2, C2.2, C3.2, C5.2, C6.2, C7.2, C8.2, C9.2, C10.2, C11.2, C12.2, C13.2, C14.2, C15.2, C16.2, C17.1, C18.1, C19.2, C20.1, C22.2, D1.2 (-), D2.2 (A), F1.2 (-), F1.4 (V-), F1.6 (-), F2.4 (V-), NPOT1.3, NPOT2.3, Q1.1 (E), Q2.1 (E), Q3.1 (E), R1k1.1, R4.1, R5.1, R7.2, R9.2, R18.1, U1.2 (GND), U2.4 (V-), U4.5 (Inh), U4.8 (VSS), U5.4 (V-), U7.7 (GND), U8.7 (GND), U9.7 (GND), U10.7 (GND), U11.3 (A), U11.4 (B), U11.5 (C), U11.6 (D), U11.8 (GND), U12.7 (GND), U13.7 (GND), U14.7 (GND), U15.7 (GND), U16.7 (GND), U17.3 (A), U17.4 (B), U17.5 (C), U17.6 (D), U17.8 (GND), U18.7 (GND), U19.1 (GND), U20.7 (GND), U22.7 (GND); also elsewhere on the board
unnamed: D2.1 (K), F1.3 (+), F1.5 (+), R3.2
unnamed: D3.2 (A), R11.1
unnamed: D3.1 (K), U5.7
unnamed: D4.2 (A), K1.A1, Q1.3 (C), R15.1
unnamed: D5.2 (A), K2.A1, Q2.3 (C)
unnamed: D6.2 (A), K3.A1, Q3.3 (C)
unnamed 66: D_BATT1.1 (K), U1.1 (IN); also elsewhere on the board
unnamed: F2.3 (+), NPOT1.2
unnamed: F2.6 (-), NPOT2.2
unnamed: D1.4, J1.2
unnamed: Q1.2 (B), R14.2
unnamed: Q2.2 (B), R16.2
unnamed: Q3.2 (B), R17.2
unnamed: 10k2.1, 10k3.2, U2.3 (+)
unnamed: 10k1.1, R1k1.2, U2.6 (-)
unnamed: C4.1, U4.6 (C1)
unnamed: C4.2, U4.7 (C2)
unnamed: U4.3 (RefIn), U4.4 (FOUT)
unnamed: R4.2, U4.11 (R1)
unnamed: R6.2, R7.1, U5.3 (+), U5.5 (+)
unnamed: R8.2, R9.1, U5.2 (-), U5.6 (-)
unnamed: C18.2, U19.5 (CV)
unnamed: R12.1, R13.1, U19.7 (DIS)
unnamed: C20.2, R13.2, U19.2 (TR), U19.6 (THR)

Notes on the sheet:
AND GATE
Block 1 - INPUTS
COUNTER_50
BOCK 3 - OUTPUT
4.10V
BLOCK 2 - FINITE STATE MACHINE
3.77V
555- TIMER/FREQUENCY
2.84V
Frequency Window
NOT GATE
RECTIFIER
Reference Low
FLIP FLOP
Battery Monitor
Reference High
OR GATE
NON-ESSENTIAL
COUNRER_05
WINDOW COMPARATOR
ESSENTIAL
GRID

Board: 2 copper layers, 84 parts (0 on the bottom side), 80 nets, no tracks yet.

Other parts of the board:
D_GRID1: 1N4007; D_DO-41_SOD81_P10.16mm_Horizontal
U3: LM358; DIP-8_W7.62mm
U6: LM393; DIP-8_W7.62mm

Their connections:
+5V: U3.8 (V+), U6.8 (V+); also elsewhere on the board
/V_RAW: D_GRID1.2 (A); also elsewhere on the board
GND: U3.4 (V-), U6.4 (V-); also elsewhere on the board
unnamed 66: D_GRID1.1 (K); also elsewhere on the board

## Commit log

2026-01-03 Initial commit: Project structure and documentation
    [schematic.kicad_pcb, schematic.kicad_sch]
2026-01-03 Add files via upload
    Fixed errors in schematic
    [schematic.kicad_sch]
2026-04-10 Reorganize project files and add supporting assets
    [class_inventory.csv, class_transient_scores.csv, csv_column_dtypes_per_file.csv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]
